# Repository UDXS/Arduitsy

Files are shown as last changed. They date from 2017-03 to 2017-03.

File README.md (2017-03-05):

# Arduitsy
## A Tiny Arduino Dev Board By David Markarian
---
### A tiny Arduino Development Board that can fit in every project and is meant to power your smaller projects (Can be programmed by Arduino)
---
#### Specs
* Reset Button
* Atmel ATtiny85 (It's Arduino Compatible!)
* 5 programmable pins
* 2 PWM pins
* 3 Analog Read pins
* All can be used as digital
* ICSP(In-Circuit Serial Programming) lets you program it with any ICSP programmer or even any Arduino using ArduinoISP (Requires jumper wires)! [Link](http://highlowtech.org/?p=1695)
* JST-PH connector which means you can connect any LiPo or Battery Pack to it

---
#### Ingredients Required
* 2x 10k ohm 0805 surface-mount resistors
* 1x .1uF 0805 surface-mount capacitor
* 1x ATtiny85 8-SOIC
* 1x 2x03 male header
* 1x Surface Mount Reset Button
* 1x 0805 LED (Orange recommended)
* 2x 1X04 stacking (male & female) headers (recommended)

OR (instead of stacking headers)
* 2x 1X04 male headers

OR
* 2x 1X04 female headers

Note: You may have to purchase larger headers then break them up

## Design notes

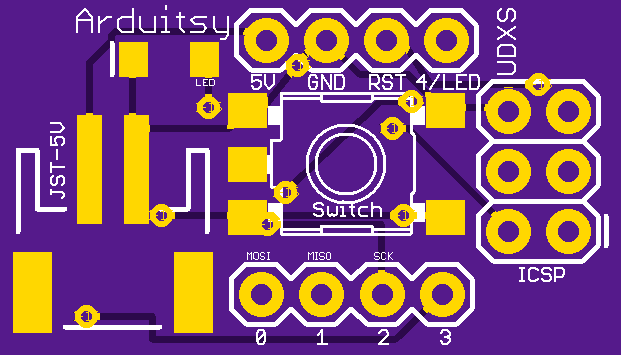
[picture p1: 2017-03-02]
eagleUp/ArduitsyR3/eagleUp_ArduitsyR3_top_board.png

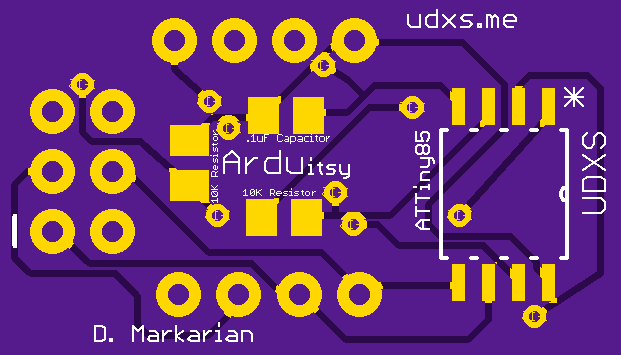
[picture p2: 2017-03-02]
eagleUp/eagleUp_ArduitsyR3_board_bottom.png

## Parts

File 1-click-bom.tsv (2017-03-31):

References | Qty | Description | Manufacturer | MPN | Manufacturer | MPN | Manufacturer | MPN | Manufacturer | MPN | Digikey | Mouser | RS | Newark | Farnell
B1 | 1 | SMT Tact Switches | TE Connectivity / AMP | 1571611-2 |  |  |  |  |  |  | EG4374CT-ND | 506FSM2JSMASTR | 7561710 | 15N4498 | 1629606
C1 | 1 | Capacitor 0805: .1uF |  | 0805YC104KAT4A |  |  |  |  |  |  | 478-7961-1-ND | 5810805YC104K |  | 94W2909
ICSP | 1 | Male 2X03 Header (Female also works) |  | 67996-406HLF |  |  |  |  |  |  | 609-3218-ND | 64967996406HLF |  | 20M2191 | 1824424
J2, J3 | 2 | Male/Female/Stacking 1X04 Header (stacking recommended) |  | SSQ-104-03-T-S |  |  |  |  |  |  | SAM1206-04-ND
LED1 | 1 | LED, Any Color (Orange recommended) |  | XZMOK54W-1 |  |  |  |  |  |  | 1497-1188-1-ND
MCU | 1 | 8-bit Microcontroller with In-System Programmable Flash |  | ATTINY85-20SU |  |  |  |  |  |  | ATTINY85-20SU-ND | 5714551641 |  | 68T3810 | 1455164
R1, R2 | 2 | RESISTOR 0805 10k ohms |  | MC0.1W08051%10K | Yageo | RC0805FR-0710KL | Panasonic | ERJ-6ENF1002V | Vishay | CRCW080510K0FKEA | P10.0KCCT-ND | 667ERJ6ENF1002V | 8123375 | 64R5370 | 1469856

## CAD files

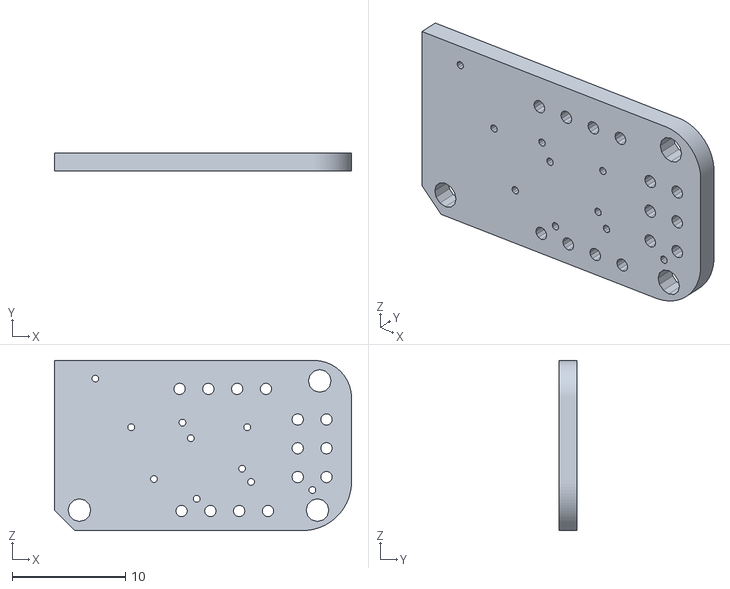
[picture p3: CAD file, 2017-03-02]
eagleUp/ArduitsyR3.obj
26.2 x 1.60 x 15.0

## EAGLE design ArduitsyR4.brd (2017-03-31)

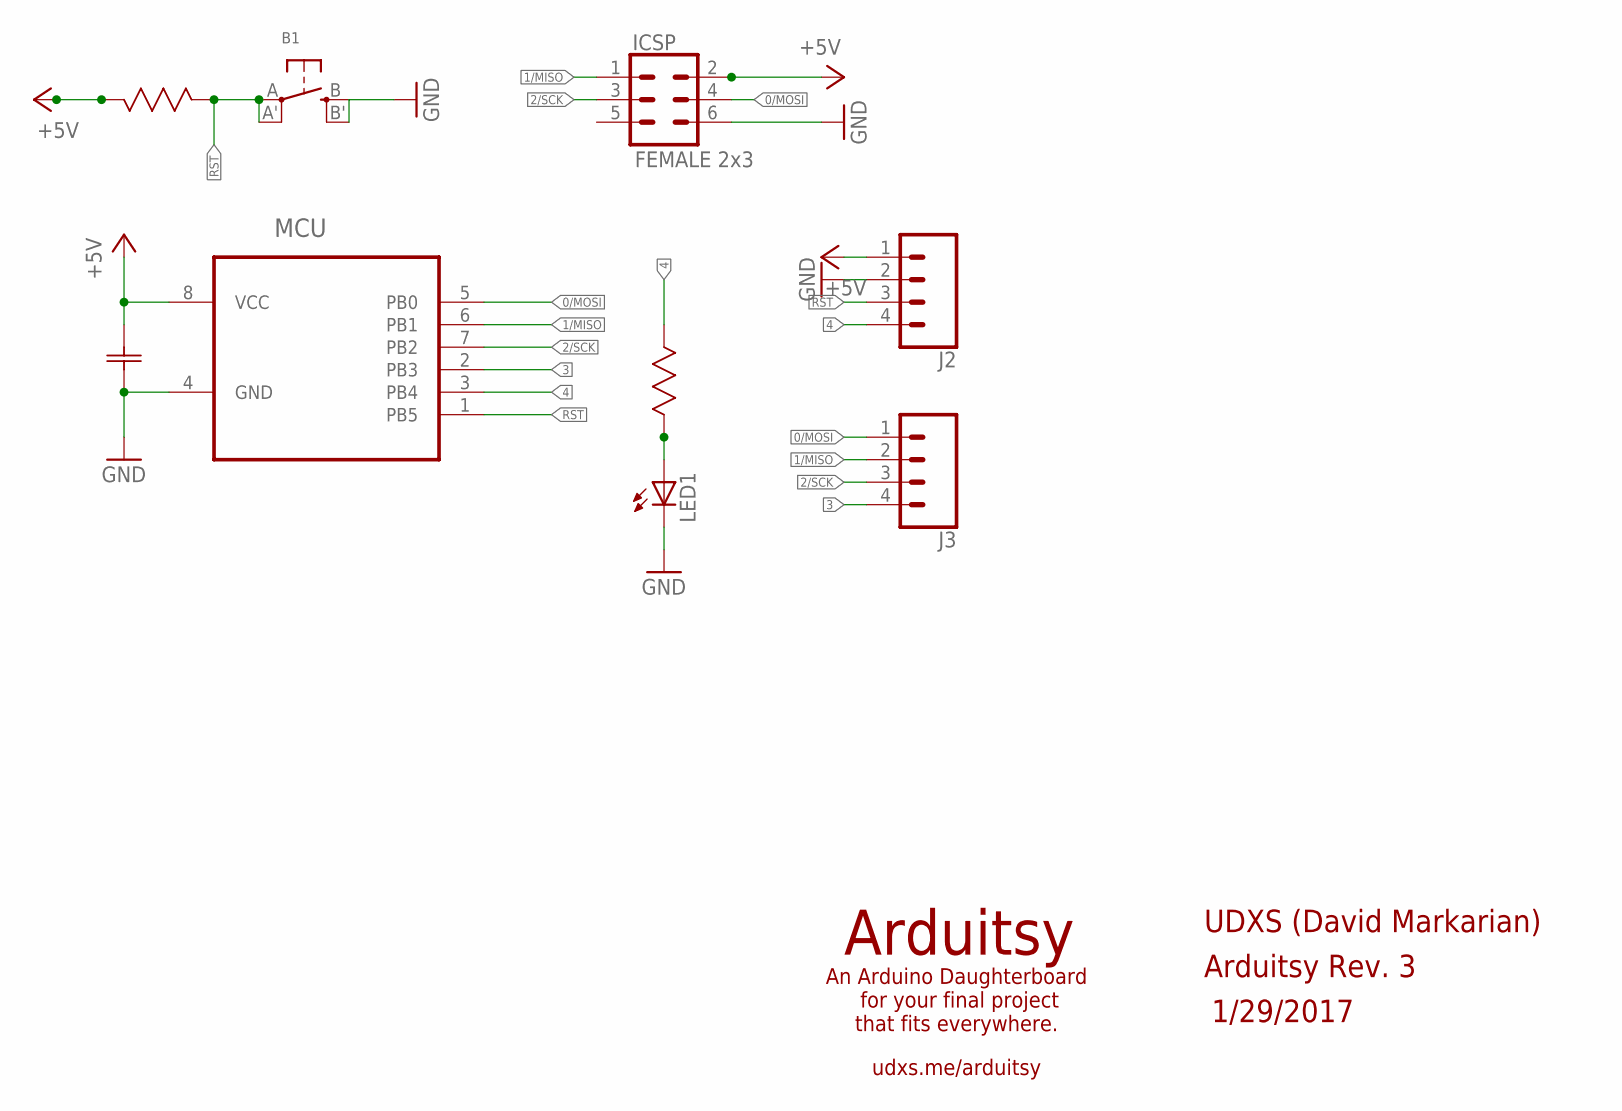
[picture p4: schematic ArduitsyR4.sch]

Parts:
B1: SWITCH_TACT_SMT; EVQ-Q2
C1: 0.1µF; CAPC2012X94N
ICSP: FEMALE 2x3; 2X3
J2, J3: CONN_04; 1X04
LED1: LEDCHIPLED_0805; CHIPLED_0805
MCU: ATTINY85-20SU; SOIC127P798X216-8N
R1, R2: 10K Ohms; RESC2013X65N

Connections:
0/MOSI: ICSP.4, J3.1, MCU.5 (PB0)
1/MISO: ICSP.1, J3.2, MCU.6 (PB1)
2/SCK: ICSP.3, J3.3, MCU.7 (PB2)
3: J3.4, MCU.2 (PB3)
4: J2.4, MCU.3 (PB4), R2.1 (R1)
+5V: C1.1 (C1), ICSP.2, J2.1, MCU.8 (VCC), R1.1 (R1)
GND: B1.B (S), B1.B' (S1), C1.2 (C2), ICSP.6, J2.2, LED1.C, MCU.4 (GND)
unnamed: LED1.A, R2.2 (R2)
RST: B1.A, B1.A' (P1), J2.3, MCU.1 (PB5), R1.2 (R2)

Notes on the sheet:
Arduitsy
An Arduino Daughterboard for your final project that fits everywhere.
udxs.me/arduitsy
UDXS (David Markarian)
1/29/2017
Arduitsy Rev. 3

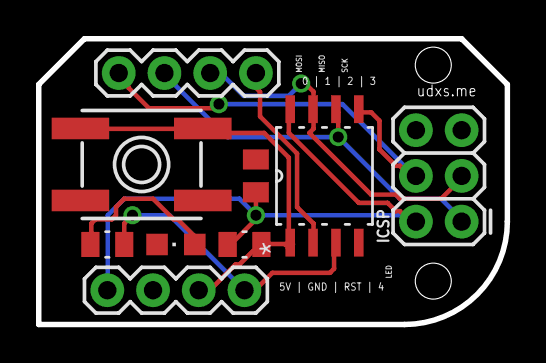
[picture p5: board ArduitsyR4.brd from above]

Board: 2 copper layers, 26.0 x 15.9 mm, 9 parts (0 on the bottom side), 9 nets.

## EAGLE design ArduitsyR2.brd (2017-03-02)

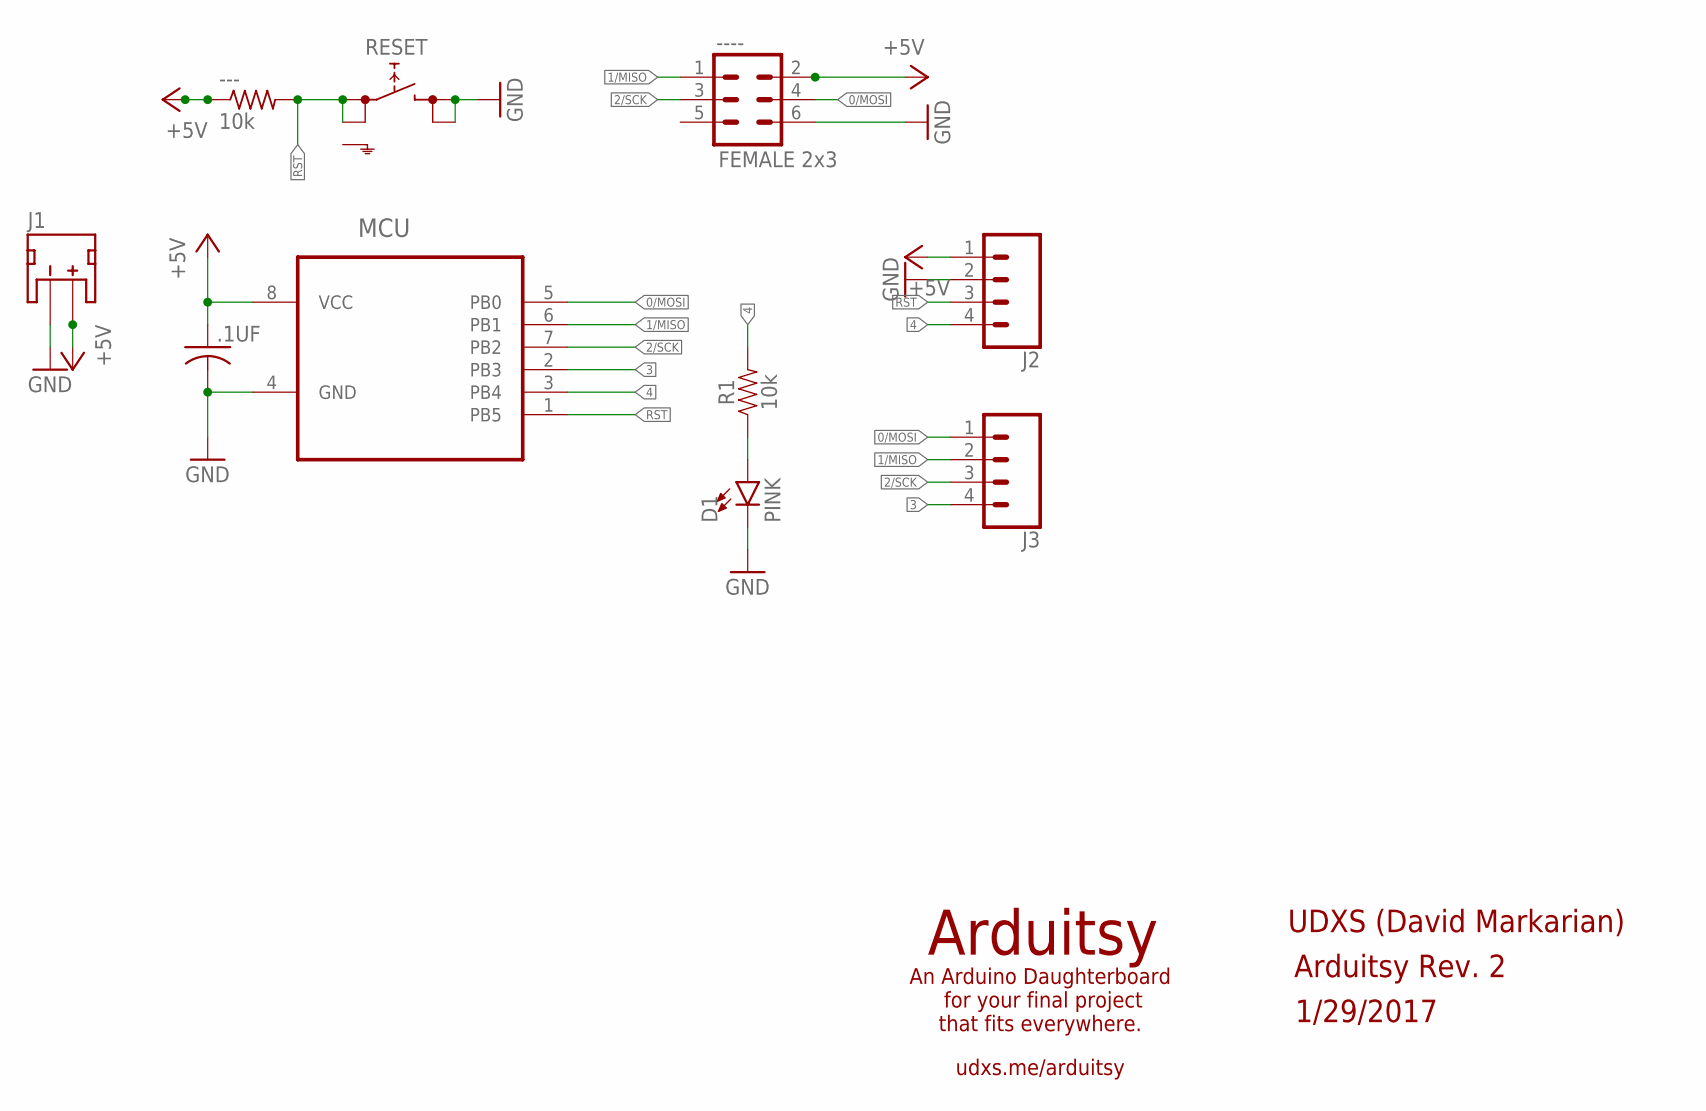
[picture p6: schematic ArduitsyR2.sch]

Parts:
---: 10k; M0805
----: FEMALE 2x3; 2X3
.1UF: C-USC0805; C0805
D1: PINK; LED-1206
J1: +5V; JST-2-SMD
J2, J3: CONN_04; 1X04
MCU: ATTINY85-20SU; SOIC127P798X216-8N
R1: 10k; 0603
RESET: SKHMPSE010; SKHMPXE010

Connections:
0/MOSI: ----.4, J3.1, MCU.5 (PB0)
1/MISO: ----.1, J3.2, MCU.6 (PB1)
2/SCK: ----.3, J3.3, MCU.7 (PB2)
3: J3.4, MCU.2 (PB3)
4: J2.4, MCU.3 (PB4), R1.2
+5V: ---.1, ----.2, .1UF.1, J1.2 (+), J2.1, MCU.8 (VCC)
GND: ----.6, .1UF.2, D1.C, J1.1 (-), J2.2, MCU.4 (GND), RESET.3 (2.1), RESET.4 (2.2)
unnamed: D1.A, R1.1
RST: ---.2, J2.3, MCU.1 (PB5), RESET.1 (1.1), RESET.2 (1.2)

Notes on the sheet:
Arduitsy
An Arduino Daughterboard for your final project that fits everywhere.
udxs.me/arduitsy
Arduitsy Rev. 2
UDXS (David Markarian)
1/29/2017

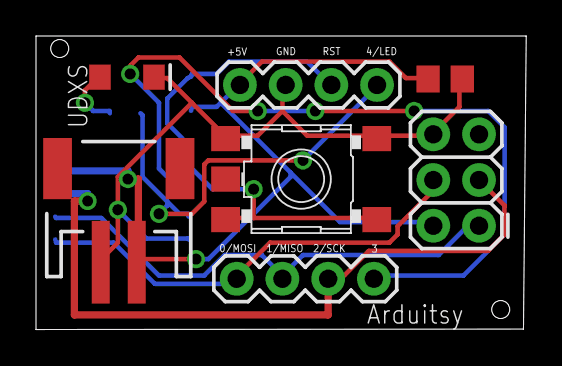
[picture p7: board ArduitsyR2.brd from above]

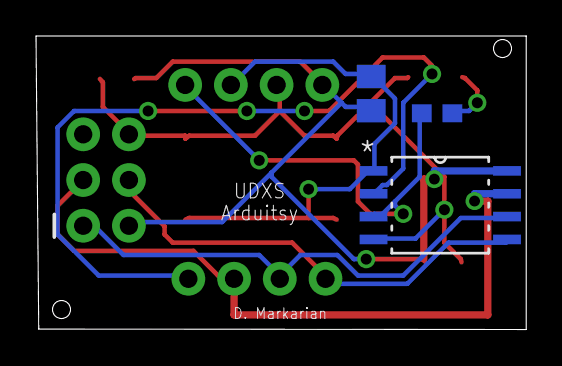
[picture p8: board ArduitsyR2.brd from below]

Board: 2 copper layers, 27.2 x 16.3 mm, 10 parts (3 on the bottom side), 9 nets.

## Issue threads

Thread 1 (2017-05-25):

What cam job did you use?

kasbah, 2017-05-25:
Hey, do you remember what CAM job you used to plot the Gerber and drill files? I wanted to recommend it to people for use with [kitnic.it](https://kitnic.it) because it actually produces drill files that are to spec.

UDXS, 2017-05-26:
CAM Jobs are confusing to me so I ended up using Autodesk's eagle brd importer and then exporting the Gerber. You might be able to find what they used at circuits.io<http://circuits.io> or maybe you can ask them.

On May 26, 2017 12:29 AM, Kaspar Emanuel <notifications@github.com&

Hey, do you remember what CAM job you used to plot the Gerber and drill files? I wanted to recommend it to people for use with kitnic.it<https://kitnic.it> because it actually produces drill files that are to spec.

—
You are receiving this because you are subscribed to this thread.
Reply to this email directly, view it on GitHub<https://github.com/UDXS/Arduitsy/issues/1>, or mute the thread<https://github.com/notifications/unsubscribe-auth/AJmihKMhy4K4sGKrEGPb69UWCHNfQPBsks5r9gDhgaJpZM4Nm96->.

Closed 2018-10-28.

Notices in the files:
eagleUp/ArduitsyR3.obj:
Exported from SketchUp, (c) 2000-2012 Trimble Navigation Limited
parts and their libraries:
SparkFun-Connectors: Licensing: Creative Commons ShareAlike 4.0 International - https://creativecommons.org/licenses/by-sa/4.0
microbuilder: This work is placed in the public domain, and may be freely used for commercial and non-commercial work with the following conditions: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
